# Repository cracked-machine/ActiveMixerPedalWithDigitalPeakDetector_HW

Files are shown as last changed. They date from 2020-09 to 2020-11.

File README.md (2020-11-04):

## Active 4-way mixer pedal with digital peak detector

- Analog 4->1 mixer circuit with buffered inputs and input gain control.
- Digital LED peak detector per input channel.
- Fits in a Hammond 1590BB enclosure (120mm x 95mm).

Required Kicad Hardware library: https://github.com/cracked-machine/KicadLibrary

Related SW project: https://github.com/cracked-machine/DigitalPeakDetector_SW

### System Overview



### Schematic

##### Top Level



##### Input Buffer and Gain Block

This uses a split supply op amp. The second stage is an inverting op amp configuration so that it can attenuate the input signal down to zero output.
Therefore the second op amp has very low input impedance and will cause "tone-suck" if used on its own. The solution is to add a preceding op amp stage in a non-inverting configuration that works as a high input impedance buffer.



##### Negative Rail Block

Each ``Input Buffer and Gain Block`` requires a split power supply. We use a charge pump to provide a negative voltage rail. The small SOT23-5 package provides ~10mA current, which is enough for a dual opamp in this design.



##### MCU Peak Detector block

This section replaces the classic analog peak detector circuit with a microcontroller. The input signal is captured by the 12bit ADC of the microcontroller. The average input value and the output threshold are determined by software. When the output threshold is reached, the microcontroller briefly toggles the LED. The on/off time duration of the LED is also determined in software.



##### MCU Input Buffer block

This serves several purposes.
1. It acts as a high impedance buffer and low pass filter for the ADC. This helps to provide a cleaner input signal for the ADC by removing high frequency noise.
2. The 3.3V *single* supply of the op amp removes any parts of the input signal that swing above 3.3v and below ground (the limits of the microcontroller). In the event that a line level input signal was plugged into the input, the op amp would be damaged before the microcontroller.



##### Power Supply block

This linear regulator drops the 9VDC input to 3.3VDC. The power requirements of the system components are very low (~65mA) so the expected dissipation is also low (0.37W). A copper pad on both sides of the PCB (with connected vias) is provided to reduce this dissipation.



## 3D Renderings

__PCB__

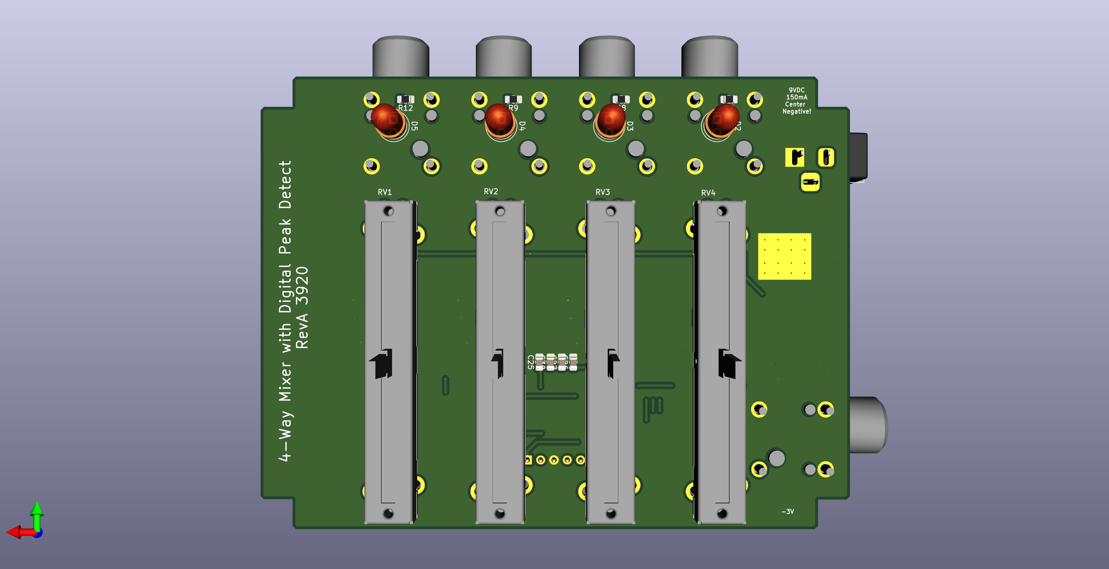
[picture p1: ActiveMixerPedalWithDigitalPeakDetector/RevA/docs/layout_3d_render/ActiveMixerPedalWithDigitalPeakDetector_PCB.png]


__Front Panel__

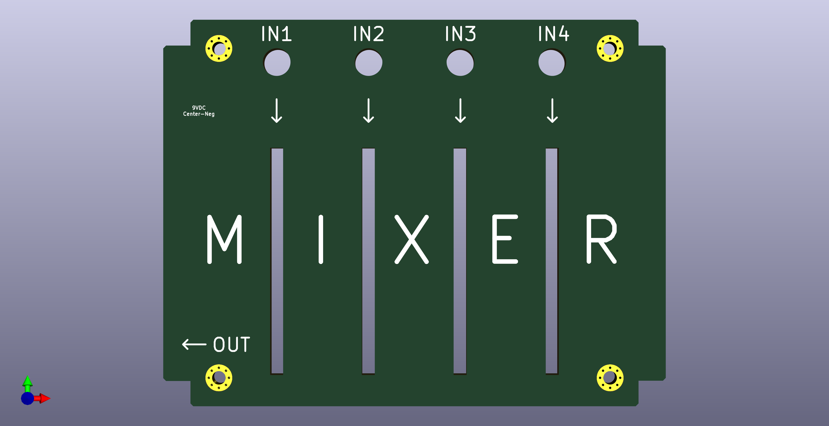
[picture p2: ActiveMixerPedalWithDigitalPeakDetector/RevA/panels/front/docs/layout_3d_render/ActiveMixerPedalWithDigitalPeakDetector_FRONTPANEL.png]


__Back Panel__

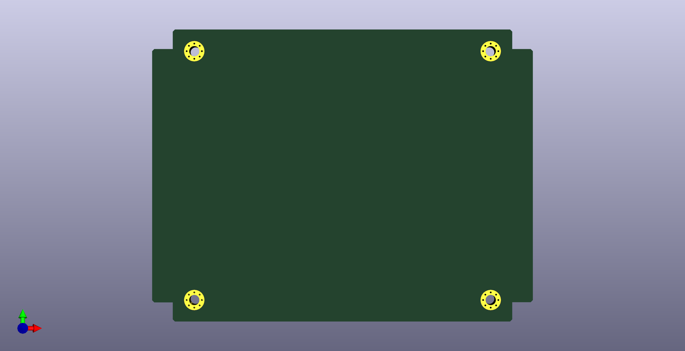
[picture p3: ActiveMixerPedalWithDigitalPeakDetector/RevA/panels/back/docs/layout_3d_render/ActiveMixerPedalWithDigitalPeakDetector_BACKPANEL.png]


__PCB and panel profile__



## TODO

Some issues with the HW design:

- The PSU uses 3.3V for both MCU and Analog blocks. This is too low for the opamps in the analog blocks and does not allow enough headroom for the signal. This can result in clipping of the signal.

- The charge pumps used by the opamps in the analog blocks (used to create a negative voltage rail) need filtering. The negative voltage rail is noisy (observed on the scope) and a high pitched whine can be heard through the output when plugged into a large amplifier. A simple passive LPF would probably solve this. 

- The output is on the wrong side!

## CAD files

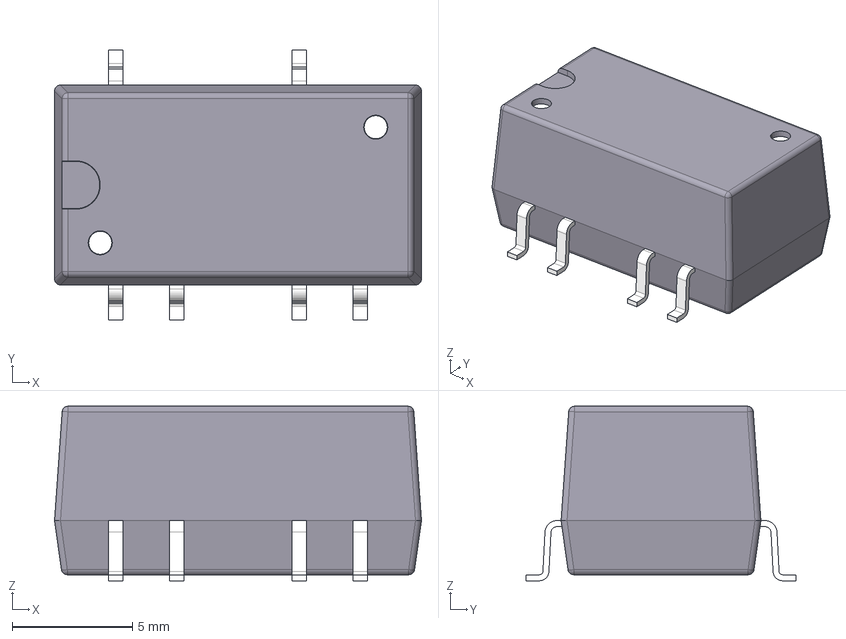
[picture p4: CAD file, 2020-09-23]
ActiveMixerPedalWithDigitalPeakDetector/RevA/3D/ISA.STEP
15.2 x 11.2 x 7.25 mm

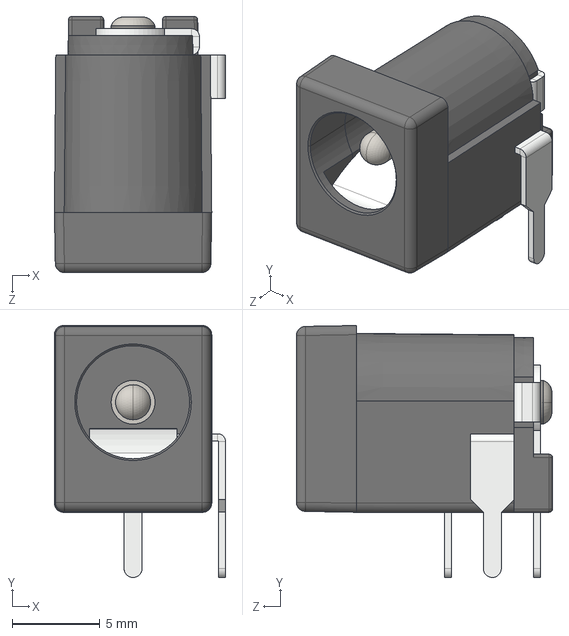
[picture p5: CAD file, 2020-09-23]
ActiveMixerPedalWithDigitalPeakDetector/RevA/3D/DC Power Jack 5.5mm x 2.1mm.STEP
9.77 x 14.4 x 14.6 mm

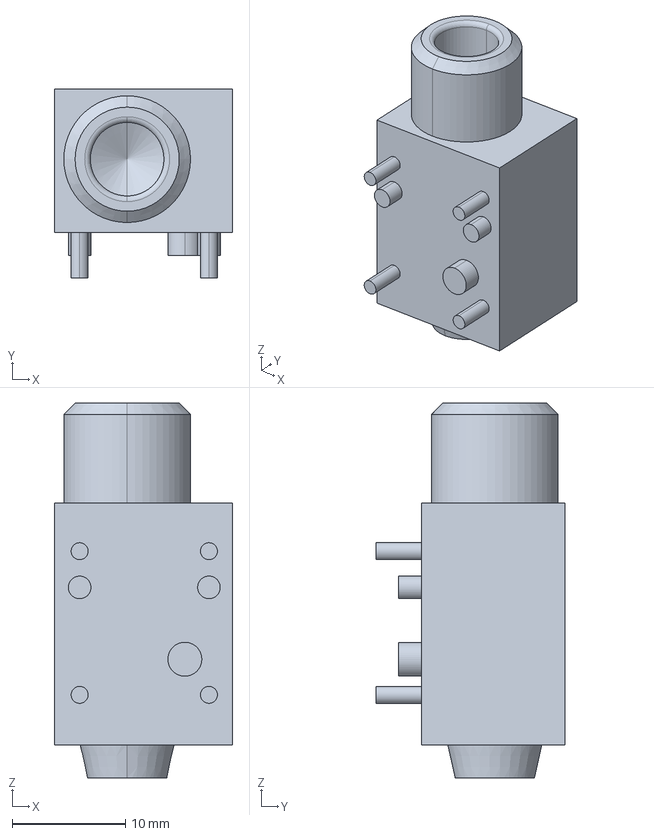
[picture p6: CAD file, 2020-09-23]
ActiveMixerPedalWithDigitalPeakDetector/RevA/3D/3D+File+NRJ4HF.stp
15.8 x 16.7 x 33.1 mm

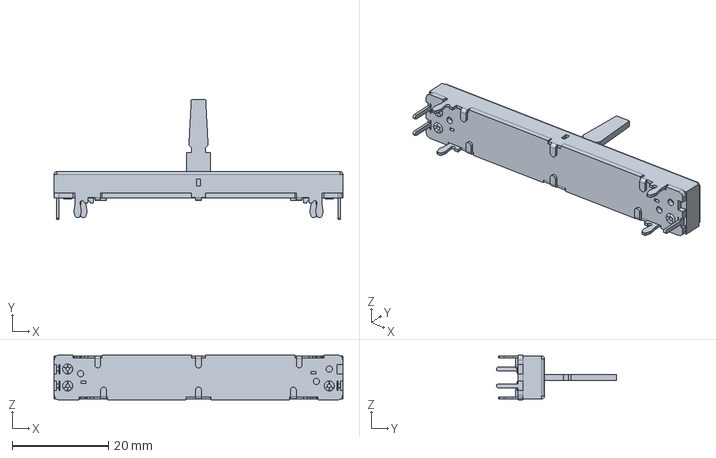
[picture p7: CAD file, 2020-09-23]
ActiveMixerPedalWithDigitalPeakDetector/RevA/3D/pta4543-2015dpb103.stp
60.0 x 25.0 x 9.30 mm

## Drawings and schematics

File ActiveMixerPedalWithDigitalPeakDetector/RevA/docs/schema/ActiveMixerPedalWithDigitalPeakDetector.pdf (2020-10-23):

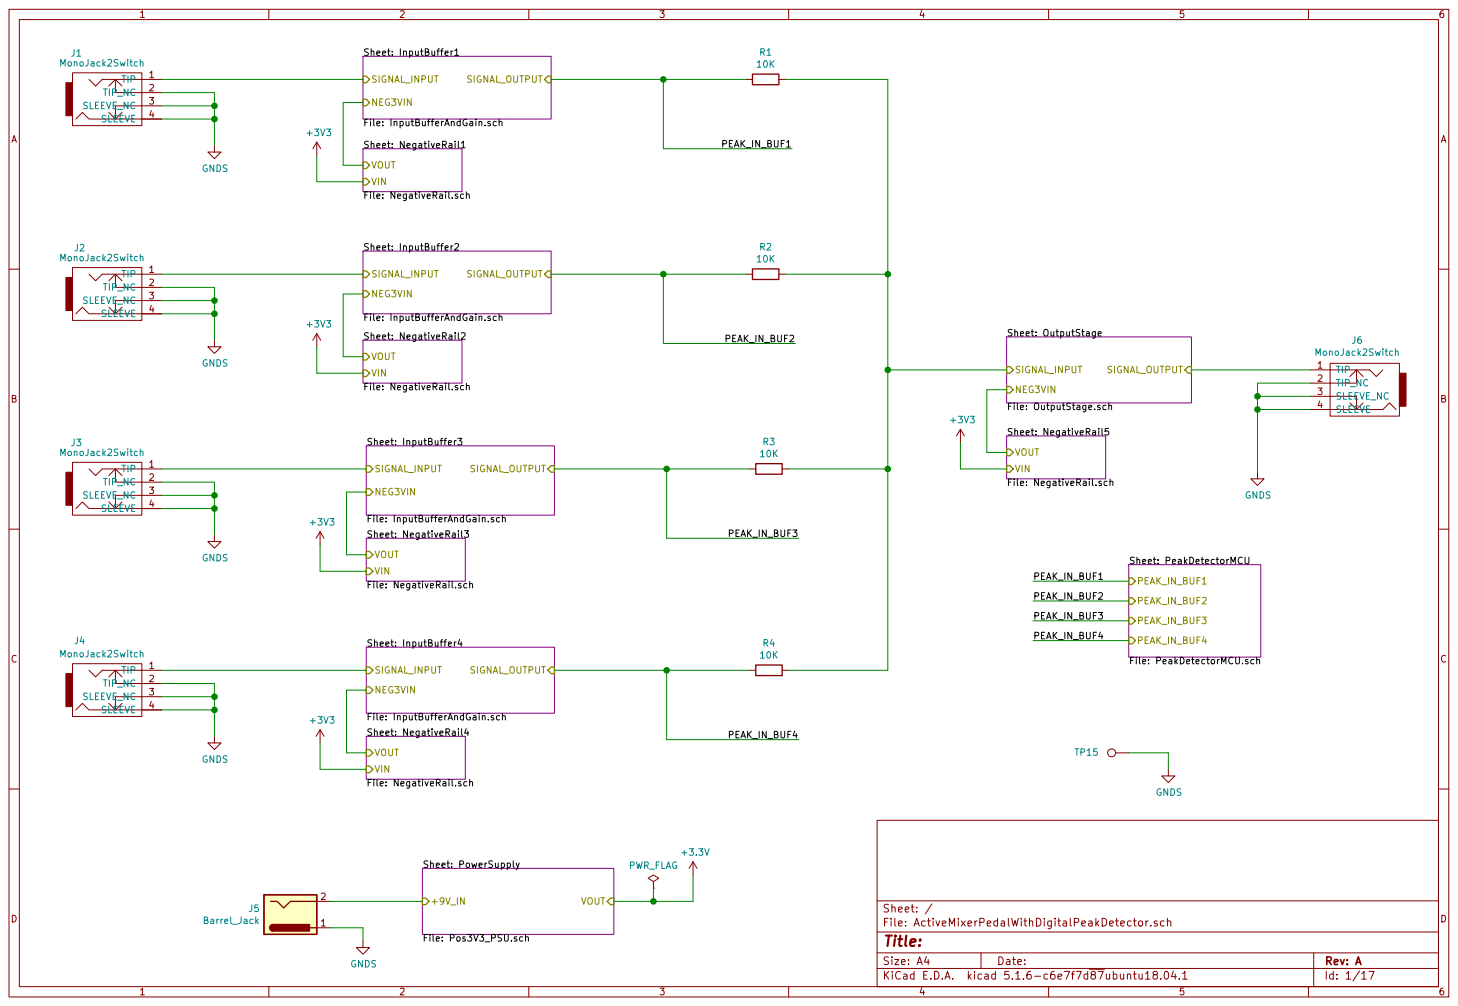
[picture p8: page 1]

File: NegativeRail.sch VIN

File: PeakDetectorMCU.sch PEAK_IN_BUF1 PEAK_IN_BUF2 PEAK_IN_BUF3 PEAK_IN_BUF4 Sheet: InputBuffer2
VOUT Sheet: InputBuffer4
VOUT Sheet: NegativeRail3

Sheet: NegativeRail5

File: ActiveMixerPedalWithDigitalPeakDetector.sch Sheet: /
Id: 1/17 Title:

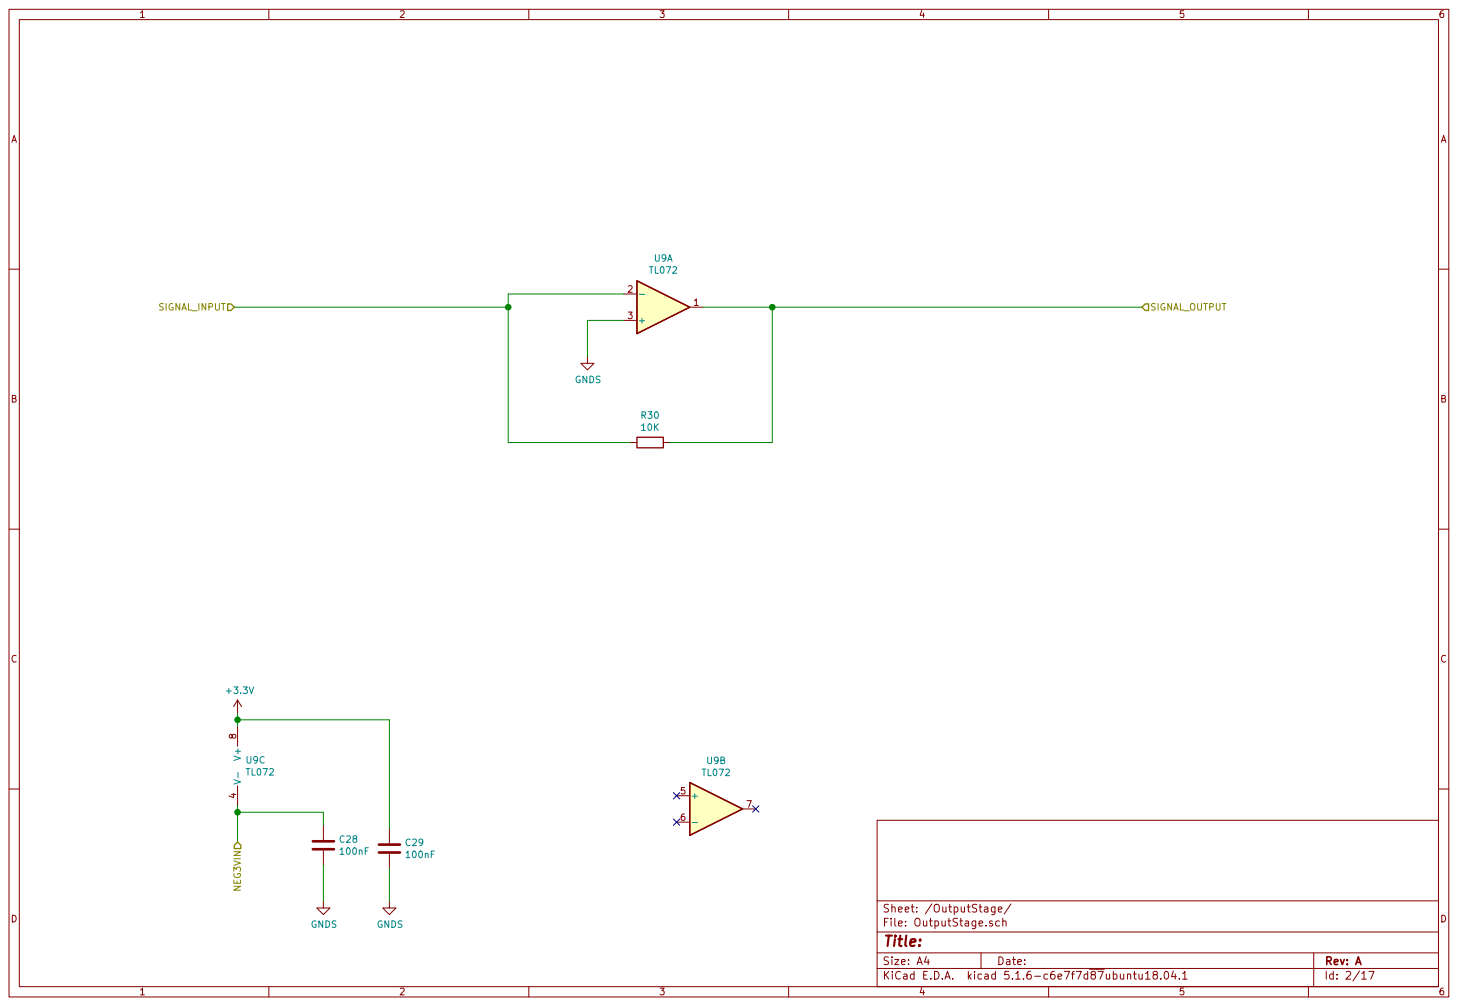
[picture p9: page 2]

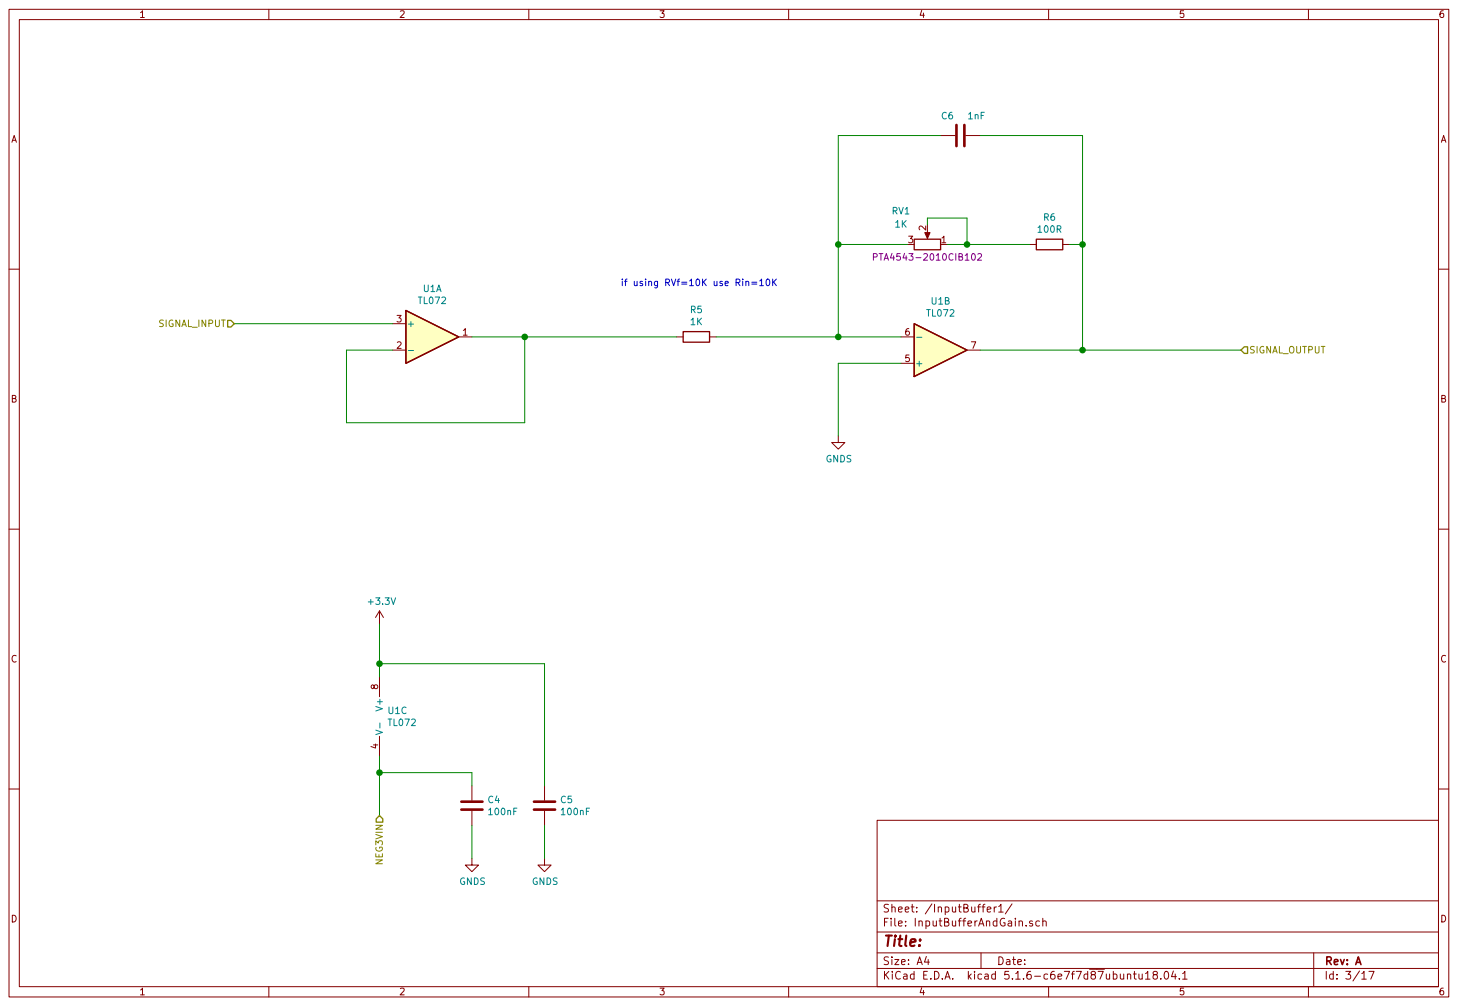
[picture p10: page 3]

if using RVf=10K use Rin=10K

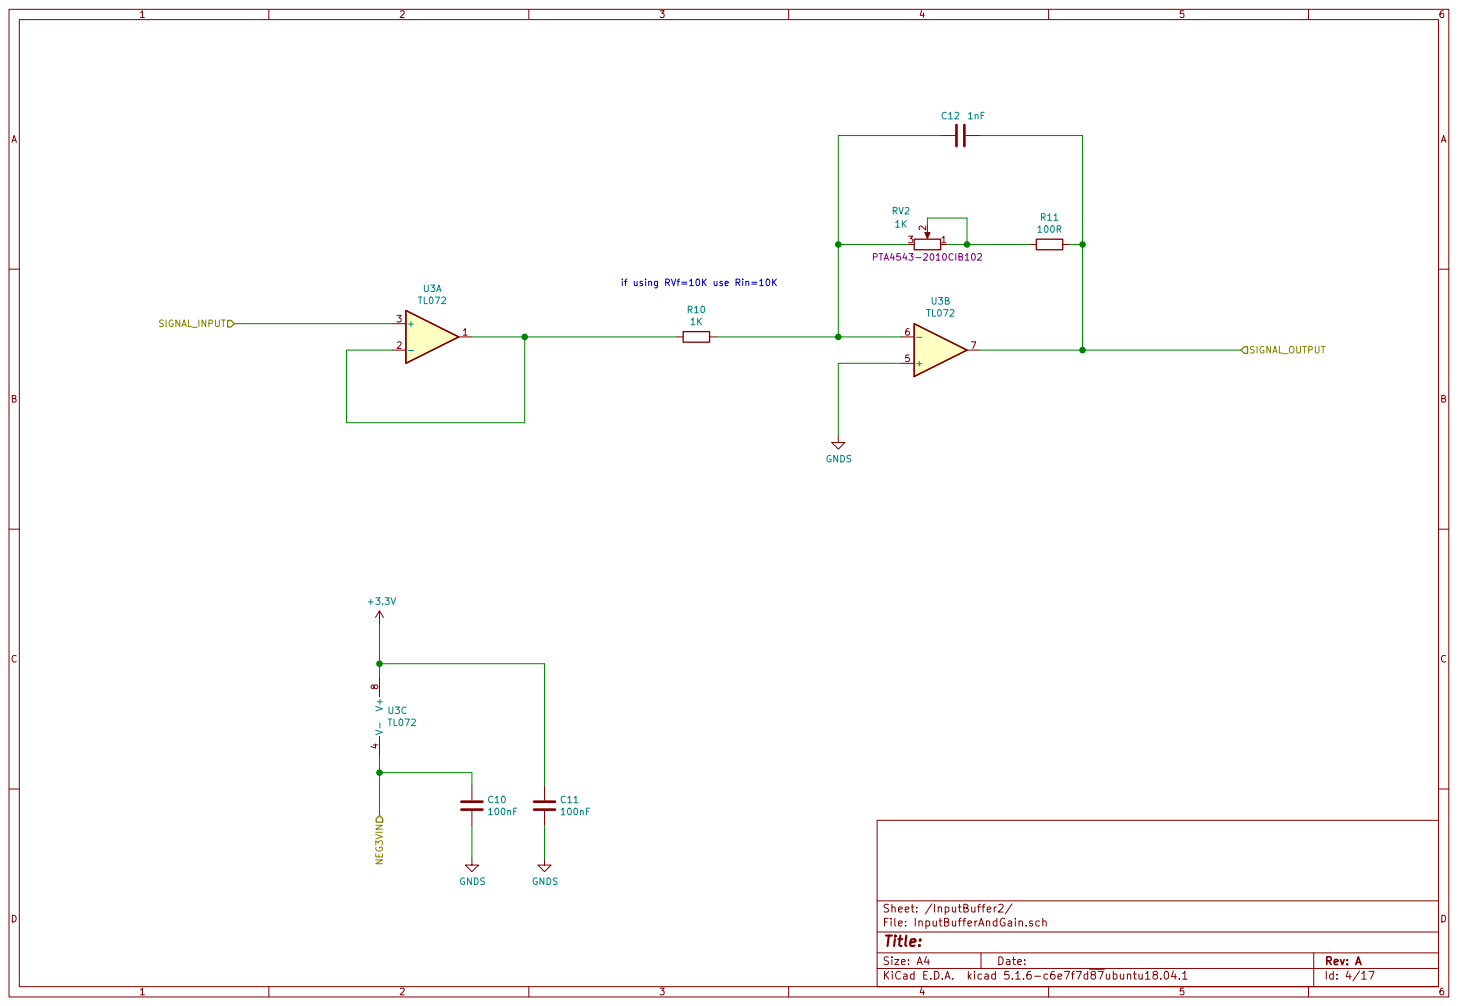
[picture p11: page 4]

if using RVf=10K use Rin=10K

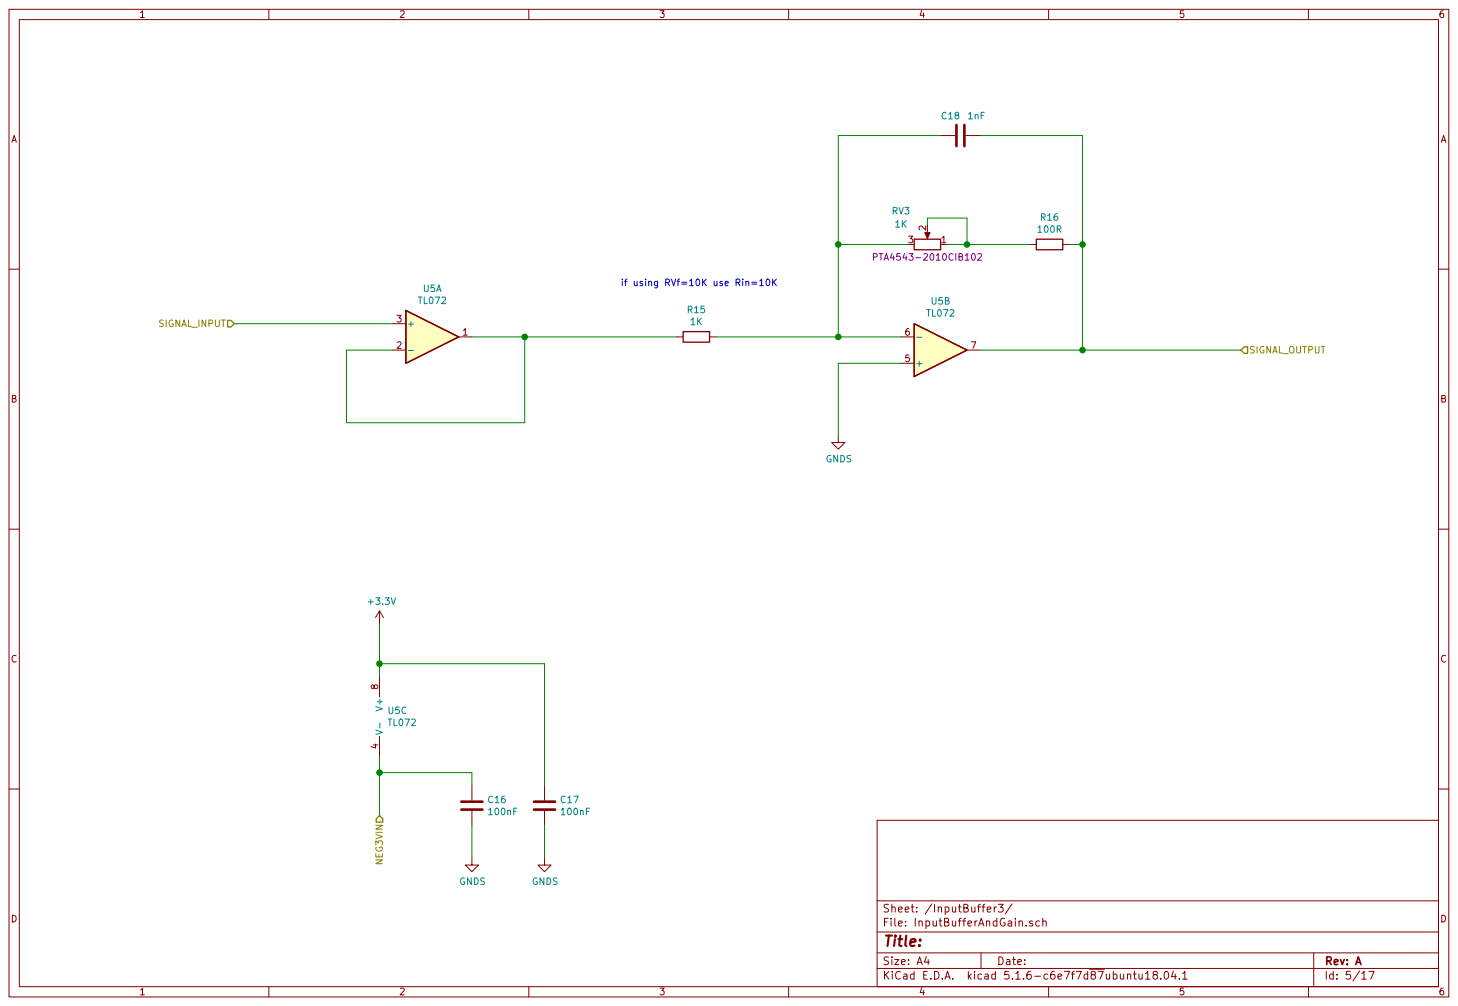
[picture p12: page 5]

if using RVf=10K use Rin=10K

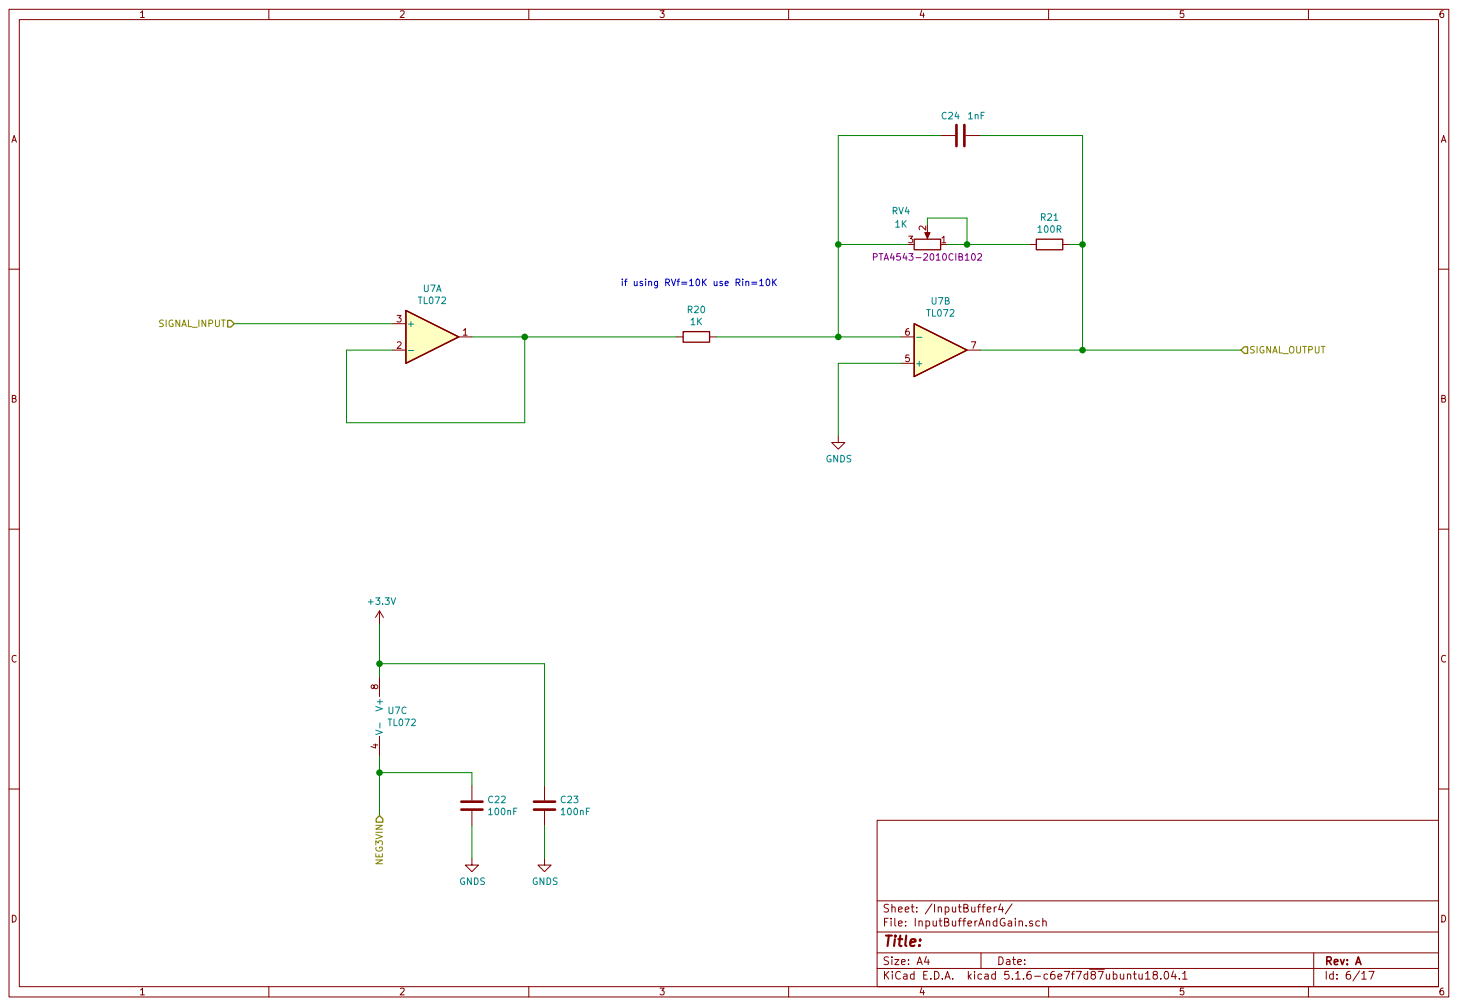
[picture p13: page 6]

if using RVf=10K use Rin=10K

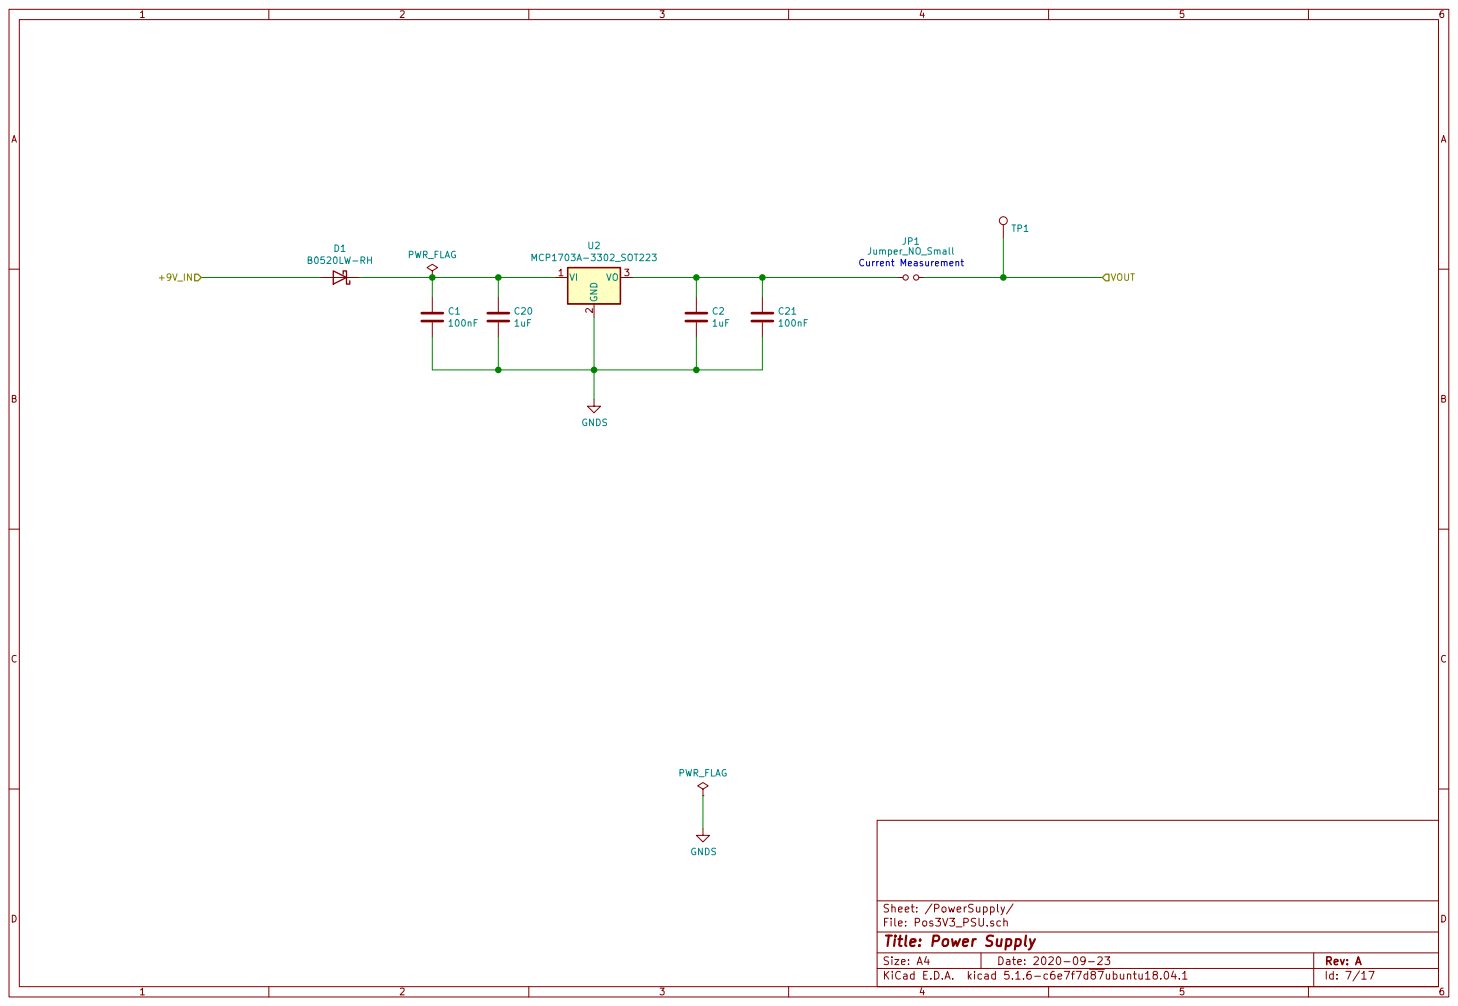
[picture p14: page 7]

Sheet: /PowerSupply/
File: Pos3V3_PSU.sch
Id: 7/17 Title: Power Supply

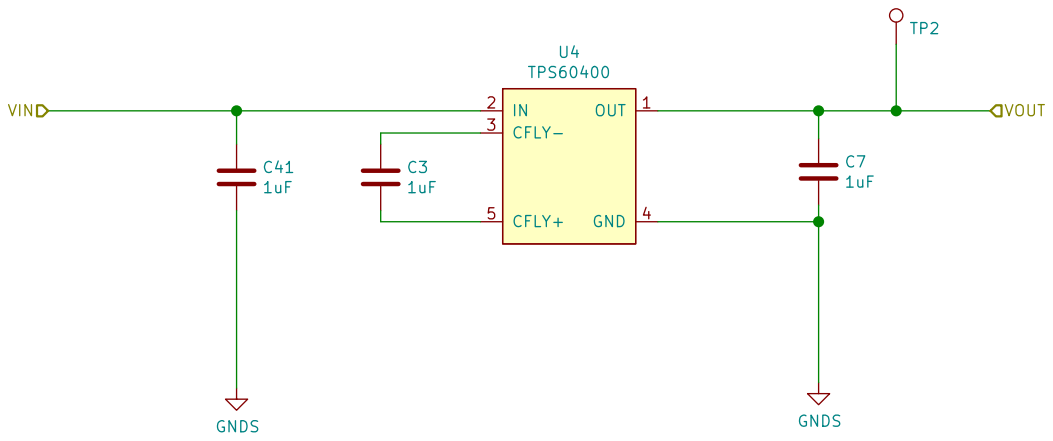
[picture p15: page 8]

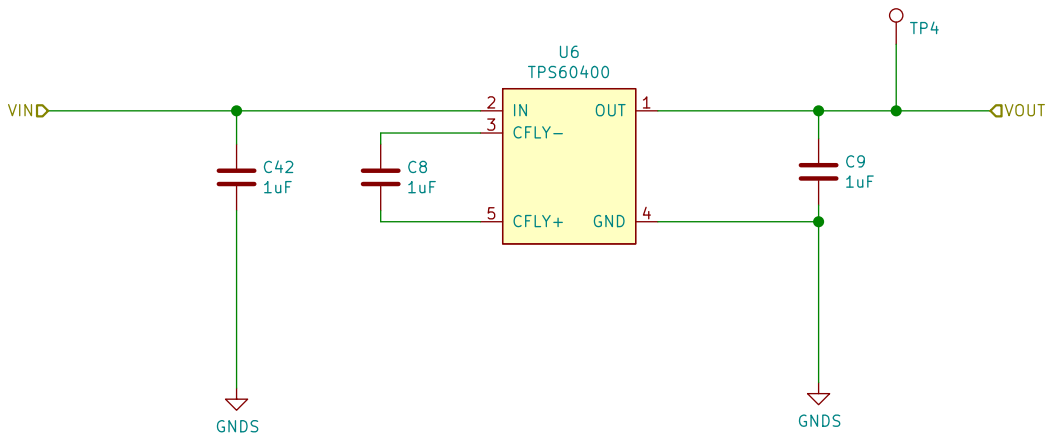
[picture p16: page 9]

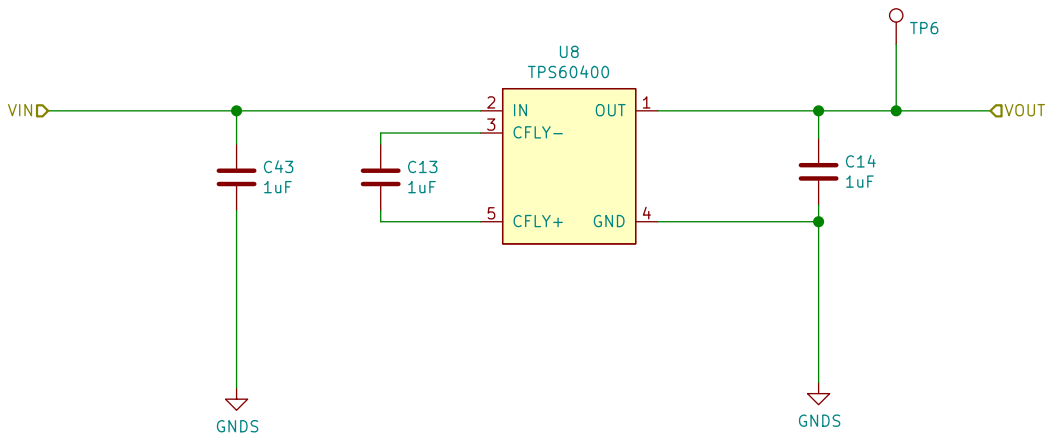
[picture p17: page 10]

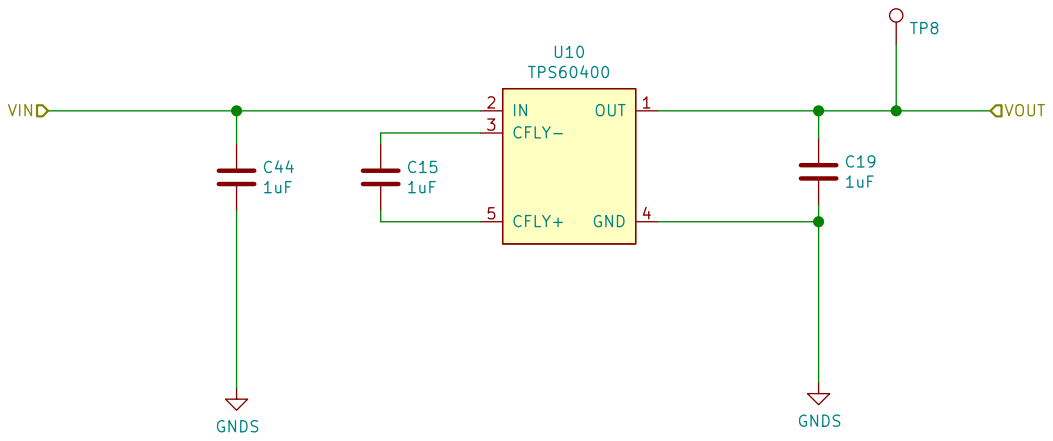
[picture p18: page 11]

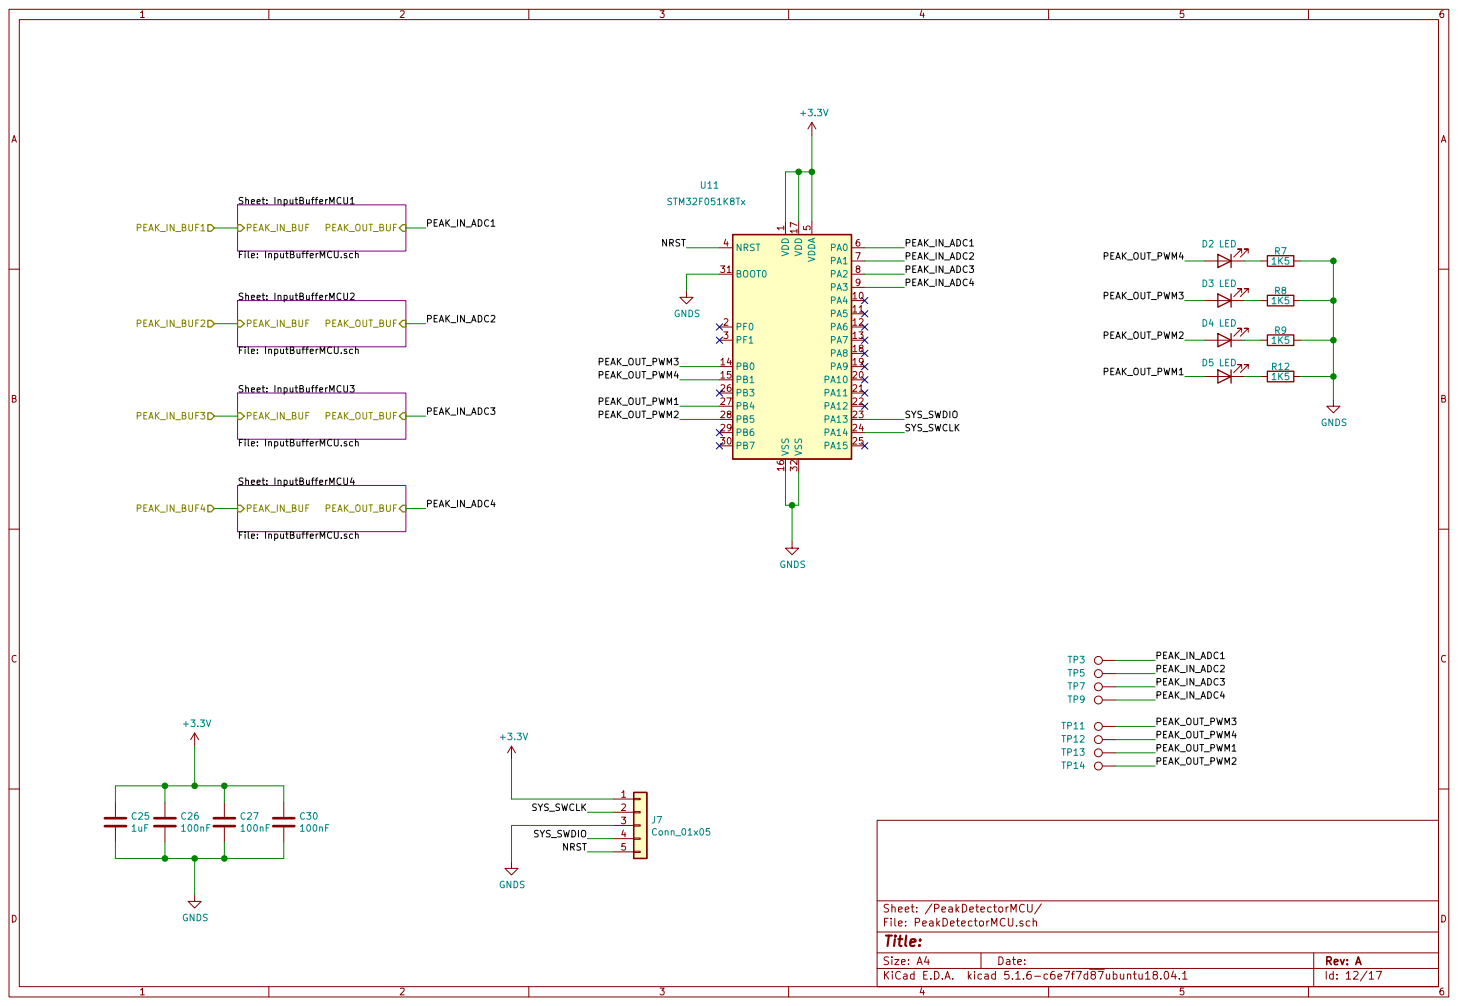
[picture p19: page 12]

1 PA4 10 PA5 11 PA6 12 PA7 13 PB0 14 PB1 15 VSS 16 VDD 17 PA8 18 PA9 19 PF0 2 PA10 20 PA11 21 PA12 22 PA13 23 PA14 24 PA15 25 PB3 26 PB4 27 PB5 28 PB6 29 PF1 3 PB7 30 BOOT0 31 VSS 32 NRST 4 VDDA

Id: 12/17 Title: File: PeakDetectorMCU.sch Sheet: /PeakDetectorMCU/






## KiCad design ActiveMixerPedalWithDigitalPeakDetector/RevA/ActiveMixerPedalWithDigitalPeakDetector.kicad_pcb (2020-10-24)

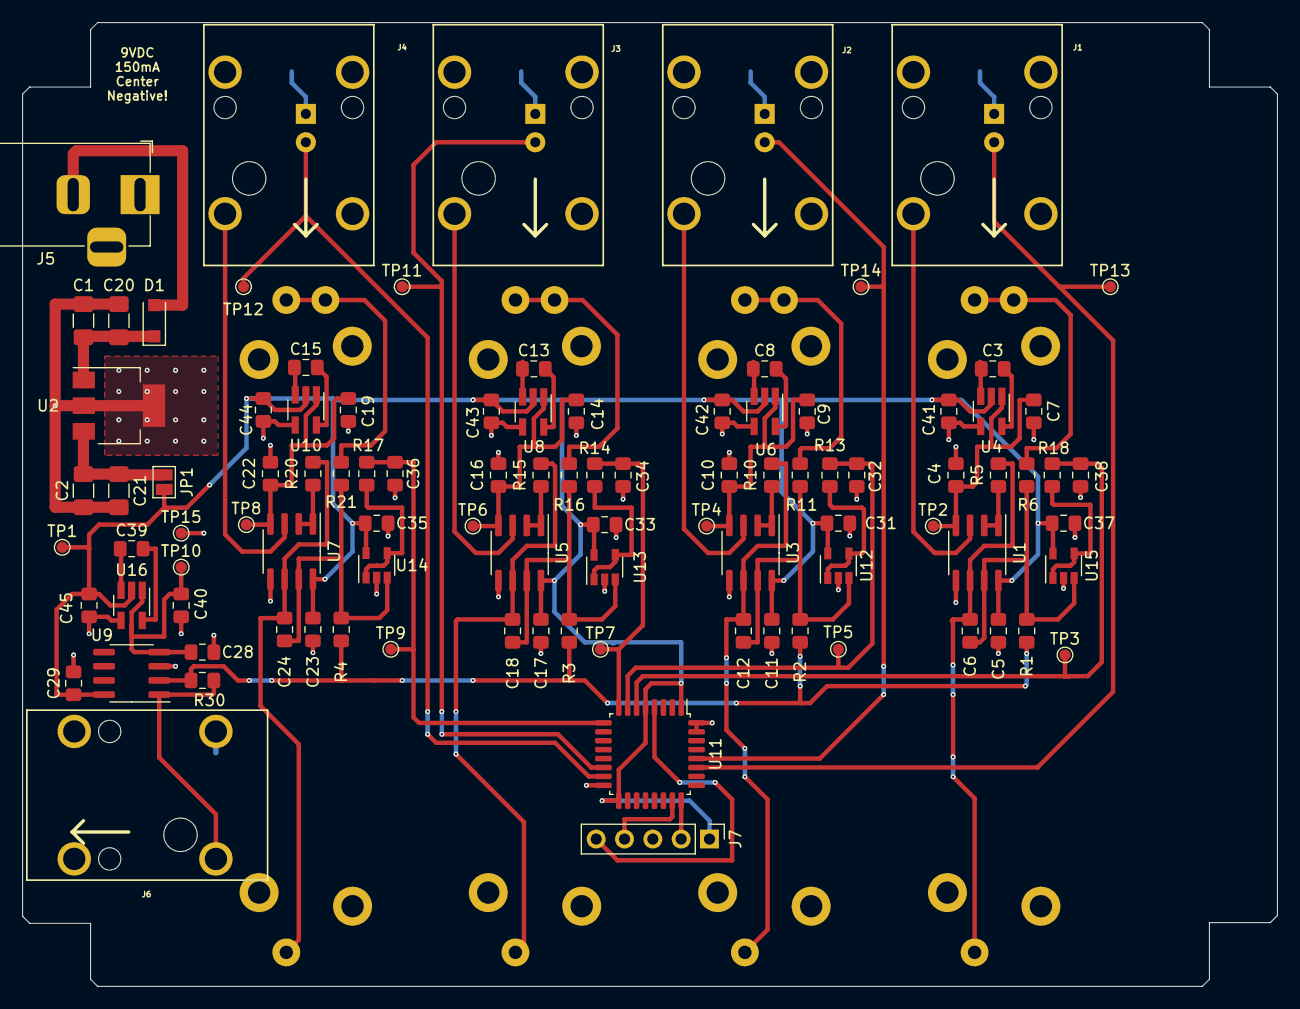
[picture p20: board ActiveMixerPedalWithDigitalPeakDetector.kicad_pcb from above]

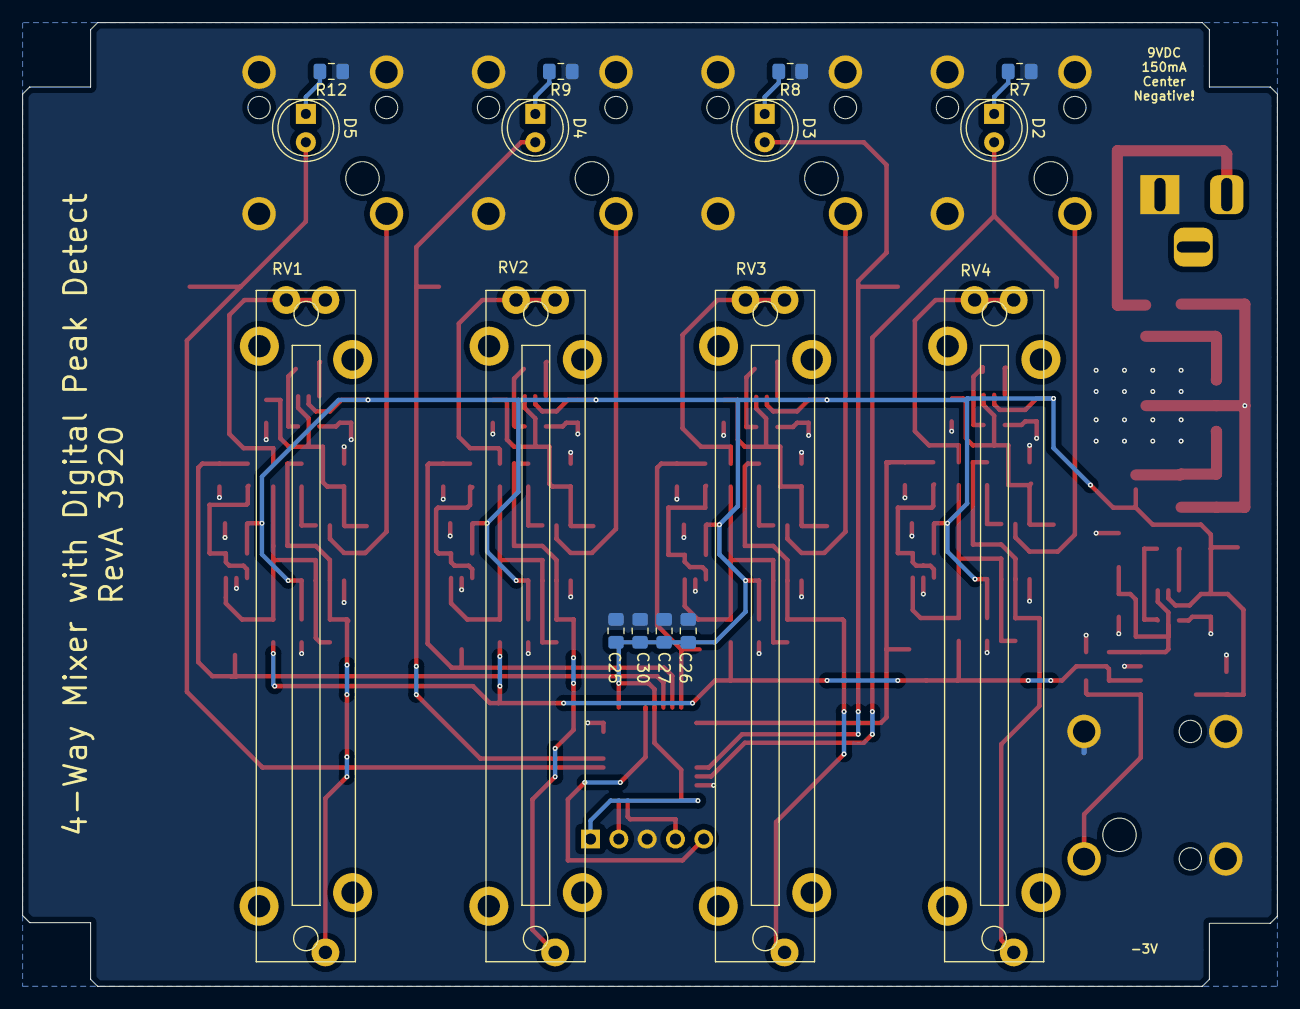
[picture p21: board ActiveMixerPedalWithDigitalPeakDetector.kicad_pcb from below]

Board: 2 copper layers, 112.5 x 86.4 mm, 114 parts (16 on the bottom side), 61 nets.

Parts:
C1, C21: 100nF; C_1206_3216Metric_Pad1.42x1.75mm_HandSolder
C2, C20: 1uF; C_1206_3216Metric_Pad1.42x1.75mm_HandSolder
C3, C7, C8, C9, C13, C14, C15, C19, C25, C39, C40, C41, C42, C43, C44, C45: 1uF; C_0805_2012Metric_Pad1.15x1.40mm_HandSolder
C4, C5, C10, C11, C16, C17, C22, C23, C26, C27, C28, C29, C30, C31, C32, C33, C34, C35, C36, C37, C38: 100nF; C_0805_2012Metric_Pad1.15x1.40mm_HandSolder
C6, C12, C18, C24: 1nF; C_0805_2012Metric_Pad1.15x1.40mm_HandSolder
D1: B0520LW-RH; D_SOD-123F
D2, D3, D4, D5: LED; LED_D5.0mm
J1, J2, J3, J4, J6: MonoJack2Switch; NRJxHx
J5: Barrel_Jack; BarrelJack_Horizontal
J7: Conn_01x05; PinHeader_1x05_P2.54mm_Vertical
JP1: Jumper_NO_Small; SolderJumper-2_P1.3mm_Open_Pad1.0x1.5mm
R1, R2, R3, R4, R30: 10K; R_0805_2012Metric_Pad1.15x1.40mm_HandSolder
R5, R10, R15, R20: 560R; R_0805_2012Metric_Pad1.15x1.40mm_HandSolder
R6, R11, R16, R21: 100R; R_0805_2012Metric_Pad1.15x1.40mm_HandSolder
R7, R8, R9, R12: R; R_0805_2012Metric_Pad1.15x1.40mm_HandSolder
R13, R14, R17, R18: 50R; R_0805_2012Metric_Pad1.15x1.40mm_HandSolder
RV1, RV2, RV3, RV4: 1K; Slider_PTA4543_60MM
TP1, TP2, TP3, TP4, TP5, TP6, TP7, TP8, TP9, TP10, TP11, TP12, TP13, TP14, TP15: TestPoint; TestPoint_Pad_D1.0mm
U1, U3, U5, U7, U9: TL072; SOIC-8_3.9x4.9mm_P1.27mm
U2: MCP1703A-3302_SOT223; SOT-223-3_TabPin2
U4, U6, U8, U10, U16: TPS60400; SOT-23-5_HandSoldering
U11: STM32F051K8Tx; LQFP-32_7x7mm_P0.8mm
U12, U13, U14, U15: MCP601-xOT; SOT-23-5

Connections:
+3V3: C5.1, C11.1, C17.1, C23.1, C25.1, C26.1, C27.1, C29.1, C30.1, C31.1, C33.1, C35.1, C37.1, C41.1, C42.1, C43.1, C44.1, C45.1, J7.1, JP1.2, TP1.1, U1.8, U3.8, U4.2, U5.8, U6.2, U7.8, U8.2, U9.8, U10.2, U11.1, U11.5, U11.17, U12.5, U13.5, U14.5, U15.5, U16.2
/InputBuffer1/NEG3VIN: C4.1, C7.1, TP2.1, U1.4, U4.1
/InputBuffer1/SIGNAL_INPUT: J1.1, U1.3
/InputBuffer2/NEG3VIN: C9.1, C10.1, TP4.1, U3.4, U6.1
/InputBuffer2/SIGNAL_INPUT: J2.1, U3.3
/InputBuffer3/NEG3VIN: C14.1, C16.1, TP6.1, U5.4, U8.1
/InputBuffer3/SIGNAL_INPUT: J3.1, U5.3
/InputBuffer4/NEG3VIN: C19.1, C22.1, TP8.1, U7.4, U10.1
/InputBuffer4/SIGNAL_INPUT: J4.1, U7.3
/OutputStage/NEG3VIN: C28.1, C40.1, TP10.1, U9.4, U16.1
/OutputStage/SIGNAL_INPUT: R1.1, R2.1, R3.1, R4.1, R30.1, U9.2
/OutputStage/SIGNAL_OUTPUT: J6.1, R30.2, U9.1
/PEAK_IN_BUF1: C6.1, R1.2, R6.1, U1.7, U15.3
/PEAK_IN_BUF2: C12.1, R2.2, R11.1, U3.7, U12.3
/PEAK_IN_BUF3: C18.1, R3.2, R16.1, U5.7, U13.3
/PEAK_IN_BUF4: C24.1, R4.2, R21.1, U7.7, U14.3
/PeakDetectorMCU/NRST: J7.5, U11.4
/PeakDetectorMCU/PEAK_IN_ADC1: C38.1, R18.1, TP3.1, U11.6
/PeakDetectorMCU/PEAK_IN_ADC2: C32.1, R13.1, TP5.1, U11.7
/PeakDetectorMCU/PEAK_IN_ADC3: C34.1, R14.1, TP7.1, U11.8
/PeakDetectorMCU/PEAK_IN_ADC4: C36.1, R17.1, TP9.1, U11.9
/PeakDetectorMCU/PEAK_OUT_PWM1: D5.2, TP13.1, U11.27
/PeakDetectorMCU/PEAK_OUT_PWM2: D4.2, TP14.1, U11.28
/PeakDetectorMCU/PEAK_OUT_PWM3: D3.2, TP11.1, U11.14
/PeakDetectorMCU/PEAK_OUT_PWM4: D2.2, TP12.1, U11.15
/PeakDetectorMCU/SYS_SWCLK: J7.2, U11.24
/PeakDetectorMCU/SYS_SWDIO: J7.4, U11.23
/PowerSupply/+9V_IN: D1.2, J5.2
GNDS: C1.2, C2.2, C4.2, C5.2, C7.2, C9.2, C10.2, C11.2, C14.2, C16.2, C17.2, C19.2, C20.2, C21.2, C22.2, C23.2, C25.2, C26.2, C27.2, C28.2, C29.2, C30.2, C31.2, C32.2, C33.2, C34.2, C35.2, C36.2, C37.2, C38.2, C40.2, C41.2, C42.2, C43.2, C44.2, C45.2, J1.2, J1.3, J1.4, J2.2, J2.3, J2.4, J3.2, J3.3, J3.4, J4.2, J4.3, J4.4, J5.1, J6.2, J6.3, J6.4, J7.3, R7.1, R8.1, R9.1, R12.1, TP15.1, U1.5, U2.2, U3.5, U4.4, U5.5, U6.4, U7.5, U8.4, U9.3, U10.4, U11.16, U11.31, U11.32, U12.2, U13.2, U14.2, U15.2, U16.4
unnamed: C1.1, C20.1, D1.1, U2.1
unnamed: C2.1, C21.1, JP1.1, U2.3
unnamed: C3.1, U4.3
unnamed: C3.2, U4.5
unnamed: C6.2, R5.1, RV1.3, U1.6
unnamed: C8.1, U6.3
unnamed: C8.2, U6.5
unnamed: C12.2, R10.1, RV2.3, U3.6
unnamed: C13.1, U8.3
unnamed: C13.2, U8.5
unnamed: C15.1, U10.3
unnamed: C15.2, U10.5
unnamed: C18.2, R15.1, RV3.3, U5.6
unnamed: C24.2, R20.1, RV4.3, U7.6
unnamed: C39.1, U16.3
unnamed: C39.2, U16.5
unnamed: D2.1, R7.2
unnamed: D3.1, R8.2
unnamed: D4.1, R9.2
unnamed: D5.1, R12.2
unnamed: R5.2, U1.1, U1.2
unnamed: R6.2, RV1.1, RV1.2
unnamed: R10.2, U3.1, U3.2
unnamed: R11.2, RV2.1, RV2.2
unnamed: R13.2, U12.1, U12.4
unnamed: R14.2, U13.1, U13.4
unnamed: R15.2, U5.1, U5.2
unnamed: R16.2, RV3.1, RV3.2
unnamed: R17.2, U14.1, U14.4
unnamed: R18.2, U15.1, U15.4
unnamed: R20.2, U7.1, U7.2
unnamed: R21.2, RV4.1, RV4.2

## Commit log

2020-09-23 hw update
    Completed RevA schematic
    TODO: complete RevA layout
    [3D+File+NRJ4HF.stp, DC Power Jack 5.5mm x 2.1mm.STEP, DigitalMixerPedal.kicad_pcb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]
2020-09-25 hw update
    RevA layout completed (draft)
    [DigitalMixerPedal.kicad_pcb, DigitalMixerPedal.sch, InputBufferAndGain.sch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]
2020-09-25 updated hw
    - added testpoints
    [DigitalMixerPedal-B_Cu.gbr, DigitalMixerPedal-B_Mask.gbr, DigitalMixerPedal-B_SilkS.gbr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]
2020-09-26 updated readme
    added schema svg
    [3D+File+NRJ4HF.stp, ActiveMixerPedalWithDigitalPeakDetector.kicad_pcb, ActiveMixerPedalWithDigitalPeakDetector.sch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]
2020-10-11 add layout dimension notes on dwg.user layer
    [ActiveMixerPedalWithDigitalPeakDetector.kicad_pcb]
2020-10-11 added front/back panel, updated readme
    [ActiveMixerPedalWithDigitalPeakDetector-B_Cu.gbr, ActiveMixerPedalWithDigitalPeakDetector-B_Mask.gbr, ActiveMixerPedalWithDigitalPeakDetector-B_SilkS.gbr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]
2020-10-12 updated front/back panel layout and gerbers
    - Changed mount holes to non-via
    - Changed BCu plane to FCu plane (same side as FCu silkscreen)
    [ActiveMixerPedalWithDigitalPeakDetector-B_Cu.gbr, ActiveMixerPedalWithDigitalPeakDetector-B_Mask.gbr, ActiveMixerPedalWithDigitalPeakDetector-B_SilkS.gbr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]
2020-10-13 added EnclosureInternalVerticalMeasurement.svg
2020-10-13 updated EnclosureInternalVerticalMeasurement.svg
2020-10-23 hardware update
    set led resistor value
    [PeakDetectorMCU.sch]
2020-10-23 schematic update
    updated resistor (Rin) to 1K/10K
    [InputBufferAndGain.sch]
2020-10-24 updated frontpanel layout
    moved silk screen
    [ActiveMixerPedalWithDigitalPeakDetector-B_Cu.gbr, ActiveMixerPedalWithDigitalPeakDetector-B_Mask.gbr, ActiveMixerPedalWithDigitalPeakDetector-B_SilkS.gbr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]
